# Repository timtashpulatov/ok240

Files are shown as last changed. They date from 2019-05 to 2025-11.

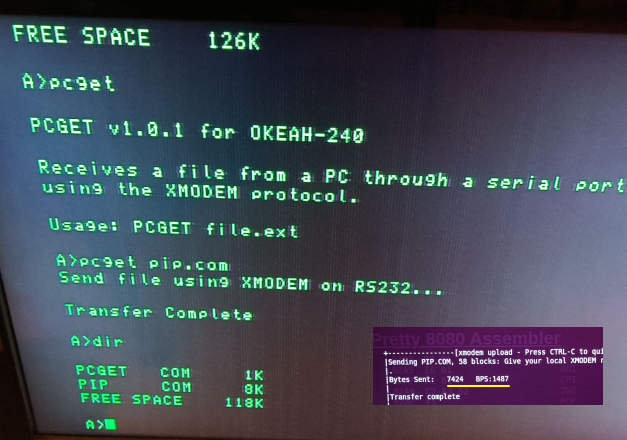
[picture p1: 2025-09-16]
pcget.png

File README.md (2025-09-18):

# ok240

https://svofski.github.io/pretty-8080-assembler/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

https://svofski.github.io/pretty-8080-assembler/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

https://svofski.github.io/pretty-8080-assembler/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

https://svofski.github.io/pretty-8080-assembler/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

https://svofski.github.io/pretty-8080-assembler/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

Literature:

<ul>
<li>https://tetris.fandom.com/wiki/Random_Generator
<li>https://zx-pk.ru/threads/23100-generator-psevdosluchajnykh-chisel/page5.html
<li>https://tetris.fandom.com/wiki/Scoring
<li>https://en.wikipedia.org/wiki/Bit_blit
</ul>

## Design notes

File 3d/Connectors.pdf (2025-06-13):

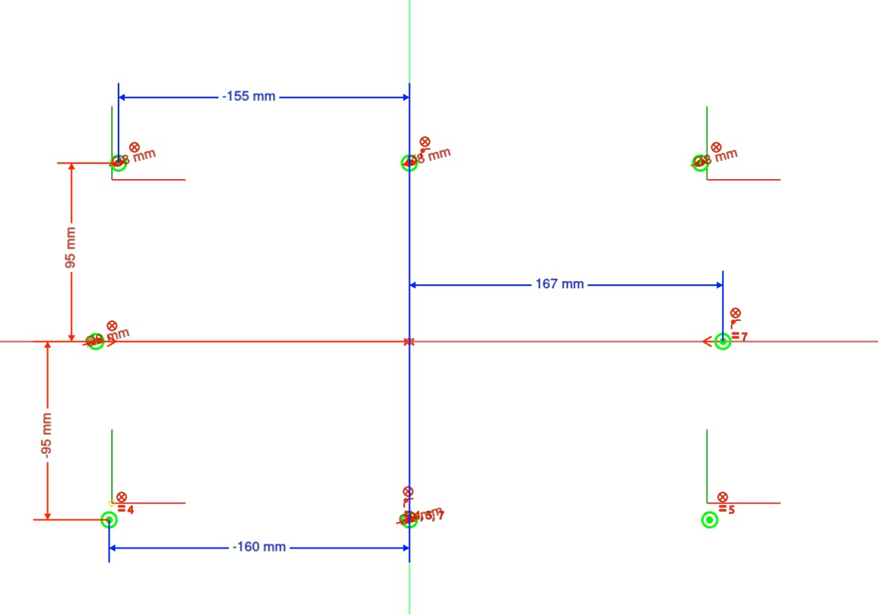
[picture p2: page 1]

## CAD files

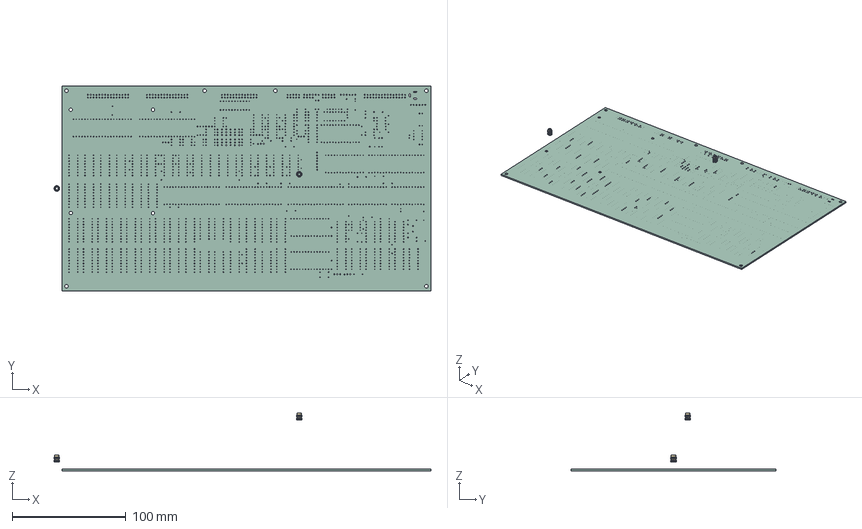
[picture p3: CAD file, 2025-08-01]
3d/Assy.FCStd
332.1 x 180.3 x 51.0 mm
OK240.2-02_PCB002
HotInsert001
HotInsert002

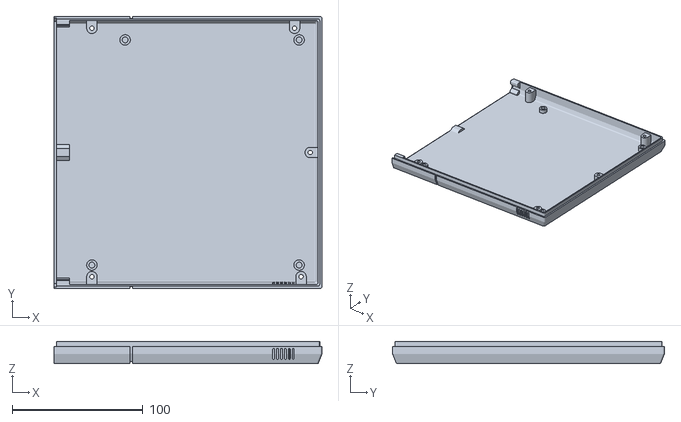
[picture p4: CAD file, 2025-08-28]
3d/stl/bottom-right-20250726.stl
205.0 x 208.0 x 17.0

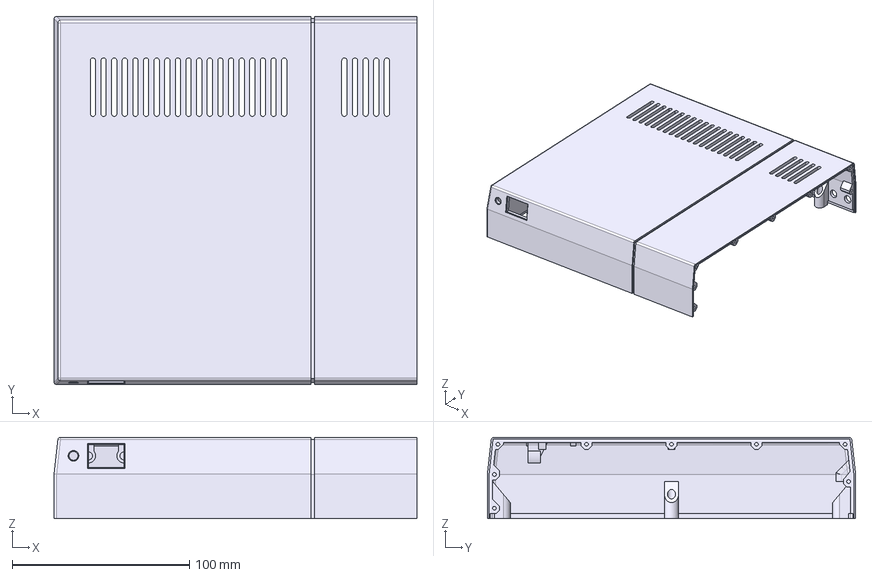
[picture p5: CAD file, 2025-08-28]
3d/TopLeft.FCStd
205.0 x 208.0 x 46.0 mm
LeftMount
FrontSupport
BackSupport
RightMount
Iface tio
Iface left (clone)001
Iface right (clone)001
Mount 1
Mount 2

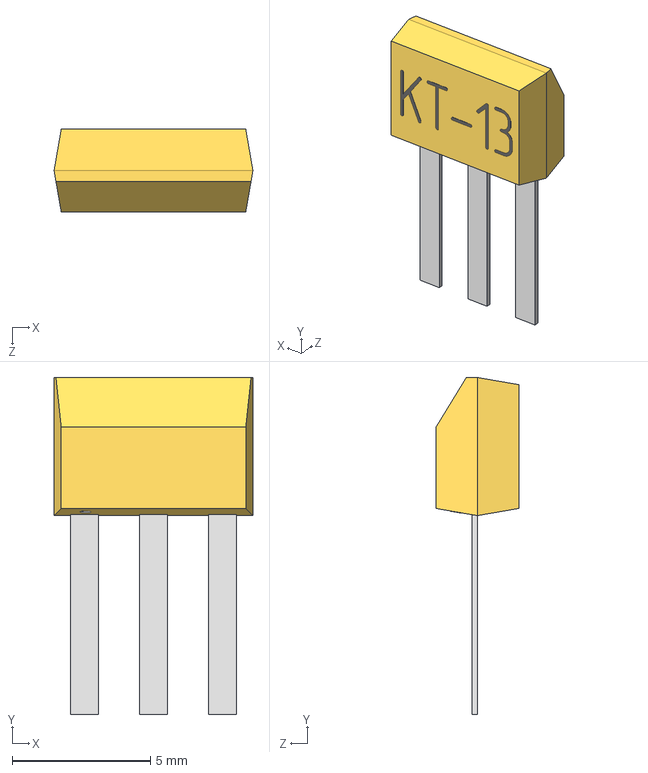
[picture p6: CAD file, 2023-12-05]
pcb/3d/КТ-13.STEP
7.20 x 12.2 x 3.01 mm
扻豵鵨
Âûâîäû ïðÿìûå x 3

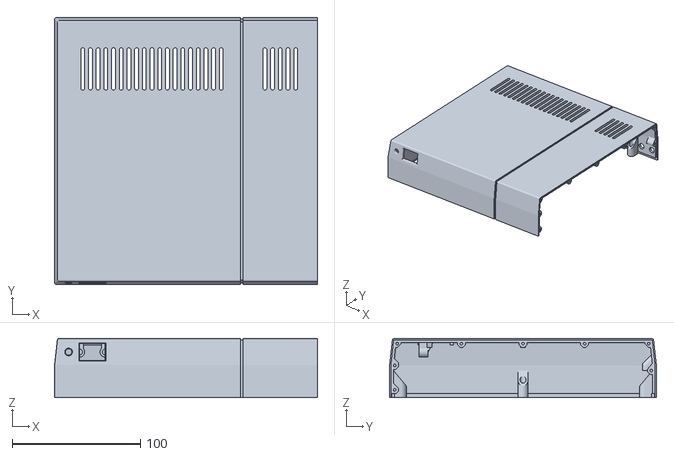
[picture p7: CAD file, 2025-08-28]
3d/stl/top-left-20250823.stl
205.0 x 208.0 x 46.0

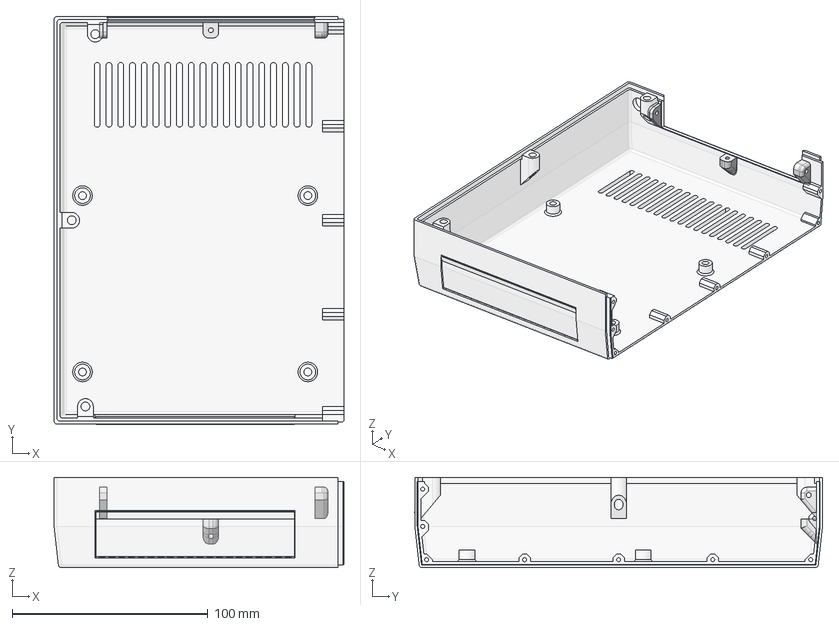
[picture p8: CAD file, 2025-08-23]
3d/TopRight.FCStd
147.9 x 208.2 x 46.0 mm
Kbd001
KbdRight (clone)
Kbd left (clone)

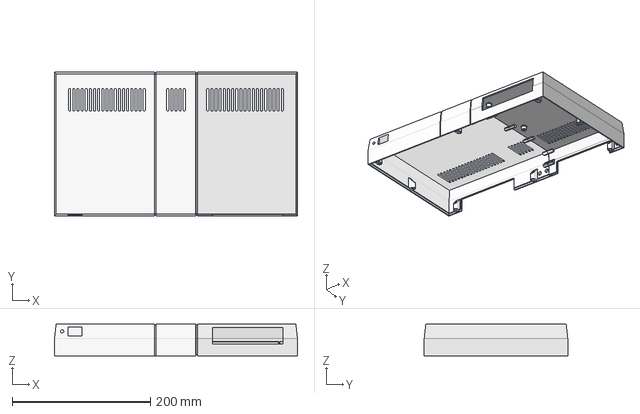
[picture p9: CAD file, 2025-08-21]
3d/CaseTopWithGrooves.FCStd
352.0 x 208.0 x 46.0 mm
Right
Left001

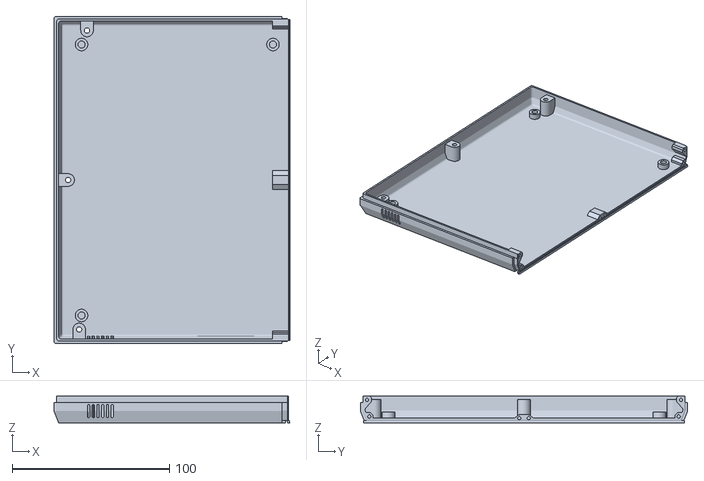
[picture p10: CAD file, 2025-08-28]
3d/stl/bottom-left-20250726.stl
150.0 x 208.0 x 17.0

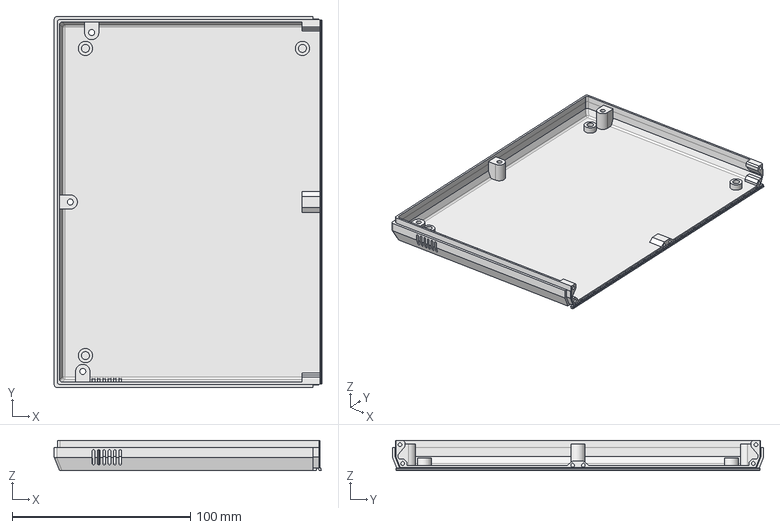
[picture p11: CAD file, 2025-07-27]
3d/CaseBottomWithGroovesAndLock.FCStd
150.0 x 208.0 x 17.0 mm

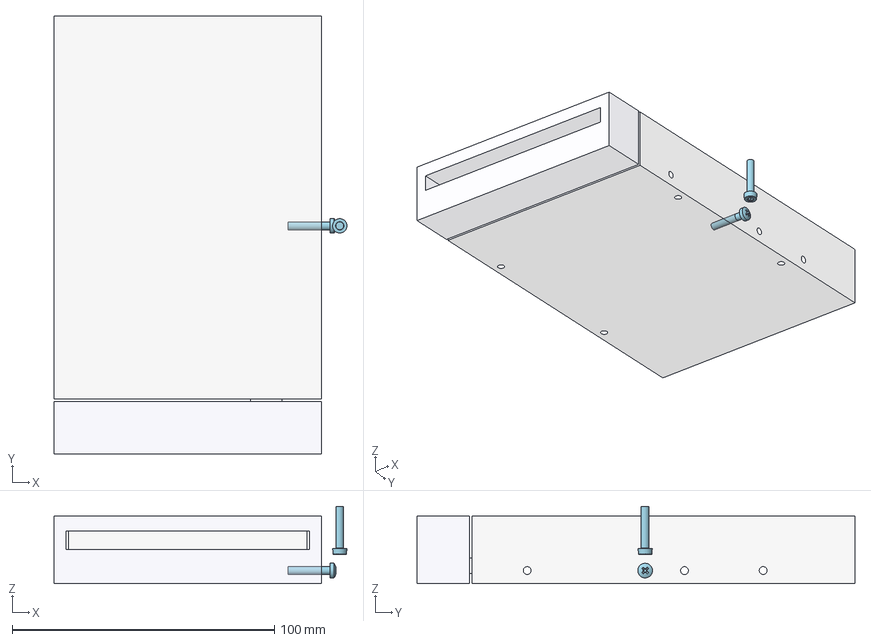
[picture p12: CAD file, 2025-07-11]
3d/FDD.FCStd
111.8 x 167.0 x 29.5 mm
M3x16-Screw
M3x16-Screw001

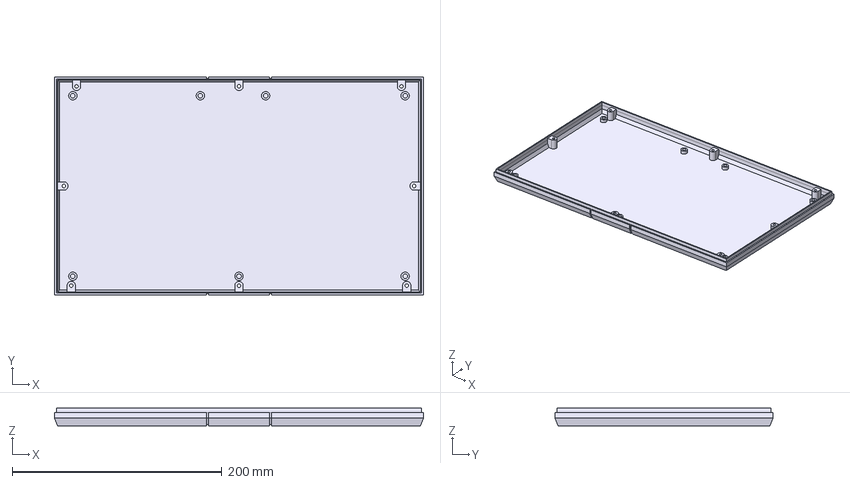
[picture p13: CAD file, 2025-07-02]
3d/CaseBottomWithGrooves.FCStd
352.0 x 208.0 x 17.0 mm

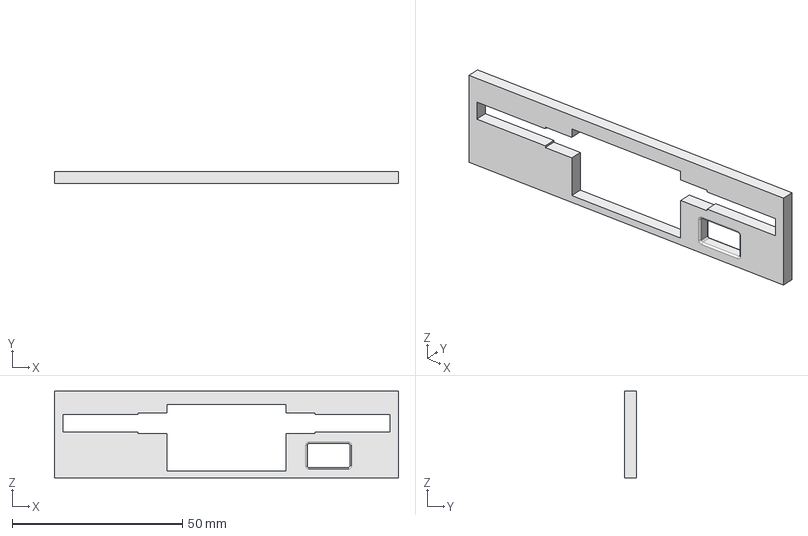
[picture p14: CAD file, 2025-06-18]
3d/Bezel.FCStd
101.0 x 3.50 x 25.4 mm

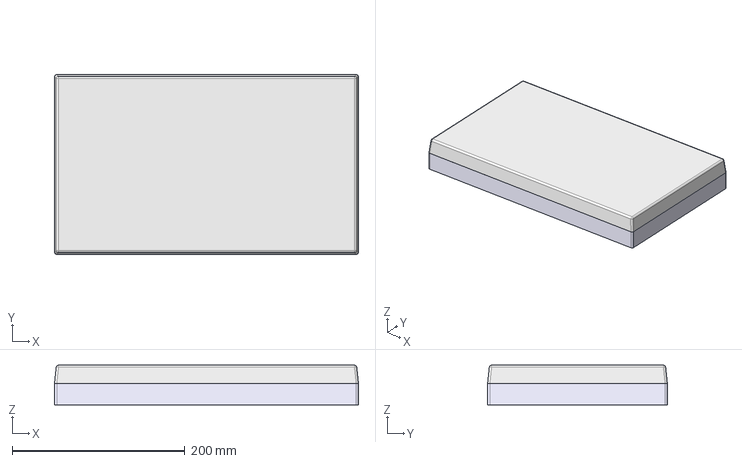
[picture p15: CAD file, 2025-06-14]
3d/CaseTopNew.FCStd
352.5 x 208.5 x 46.0 mm
Top
Mid

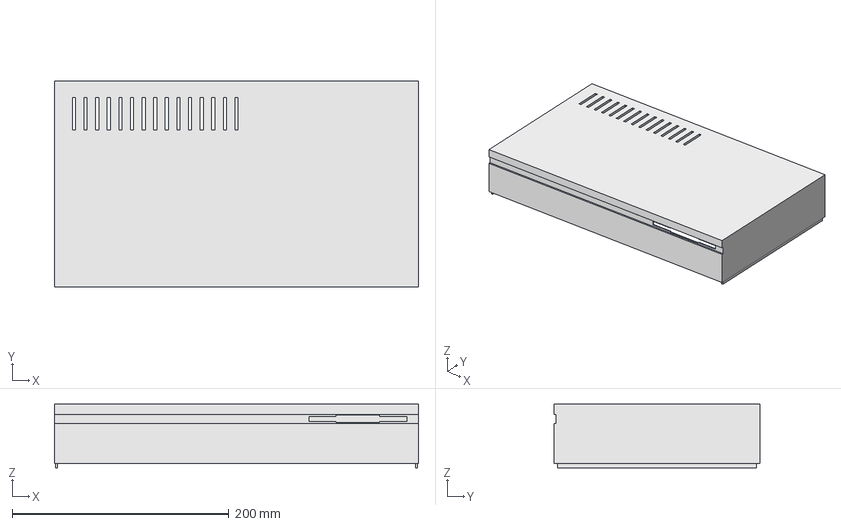
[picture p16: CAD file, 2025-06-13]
3d/CaseTop.FCStd
336.0 x 190.0 x 59.0 mm

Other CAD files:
3d/stl/top-right-20250823.stl
3d/CaseTopNewSolid.FCStd
3d/CaseBottom.FCStd
3d/FloppyFrame.FCStd
3d/FDC.FCStd
3d/PCB.FCStd

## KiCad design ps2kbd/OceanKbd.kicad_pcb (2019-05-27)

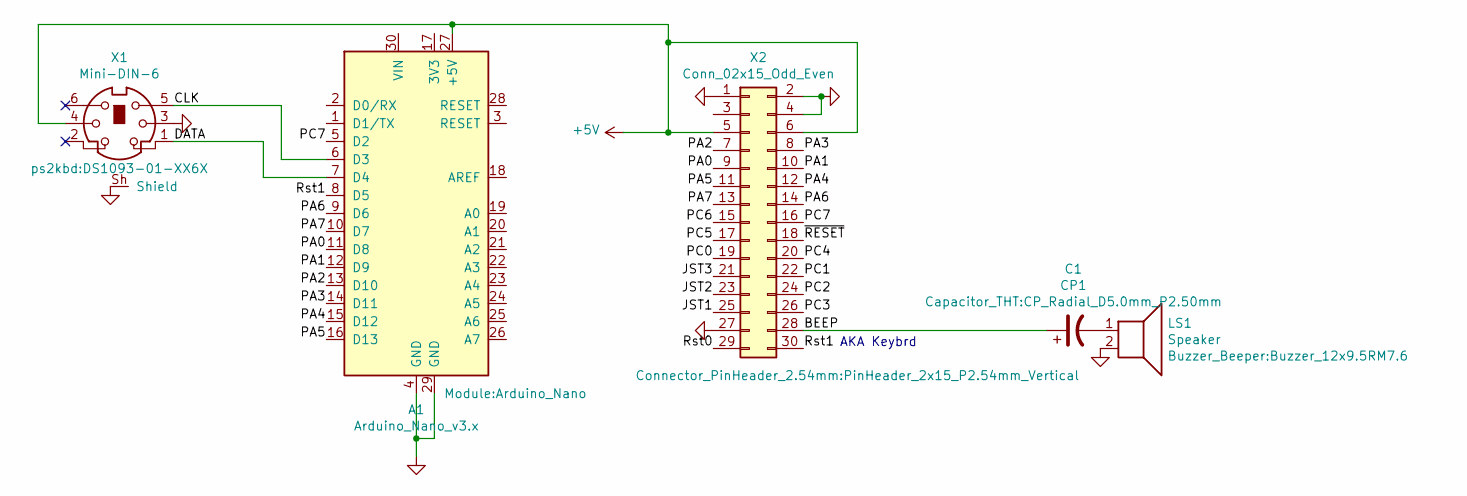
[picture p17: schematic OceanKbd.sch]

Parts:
A1: Arduino_Nano_v3.x; Arduino_Nano
C1: CP1; CP_Radial_D5.0mm_P2.50mm
LS1: Speaker; Buzzer_12x9.5RM7.6
X1: Mini-DIN-6; DS1093-01-XX6X
X2: Conn_02x15_Odd_Even; PinHeader_2x15_P2.54mm_Vertical

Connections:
+5V: A1.27 (+5V), X1.4, X2.5, X2.6
/BEEP: C1.1, X2.28
/CLK: A1.6 (D3), X1.5
/DATA: A1.7 (D4), X1.1
/JST1: X2.25
/JST2: X2.23
/JST3: X2.21
/PA0: A1.11 (D8), X2.9
/PA1: A1.12 (D9), X2.10
/PA2: A1.13 (D10), X2.7
/PA3: A1.14 (D11), X2.8
/PA4: A1.15 (D12), X2.12
/PA5: A1.16 (D13), X2.11
/PA6: A1.9 (D6), X2.14
/PA7: A1.10 (D7), X2.13
/PC0: X2.19
/PC1: X2.22
/PC2: X2.24
/PC3: X2.26
/PC4: X2.20
/PC5: X2.17
/PC6: X2.15
/PC7: A1.5 (D2), X2.16
/Rst0: X2.29
/Rst1: A1.8 (D5), X2.30
/~RESET: X2.18
GND: A1.4 (GND), A1.29 (GND), LS1.2, X1.3, X1.SH, X1.Sh (Shield), X2.1, X2.2, X2.4, X2.27
unnamed: C1.2, LS1.1

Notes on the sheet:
AKA Keybrd

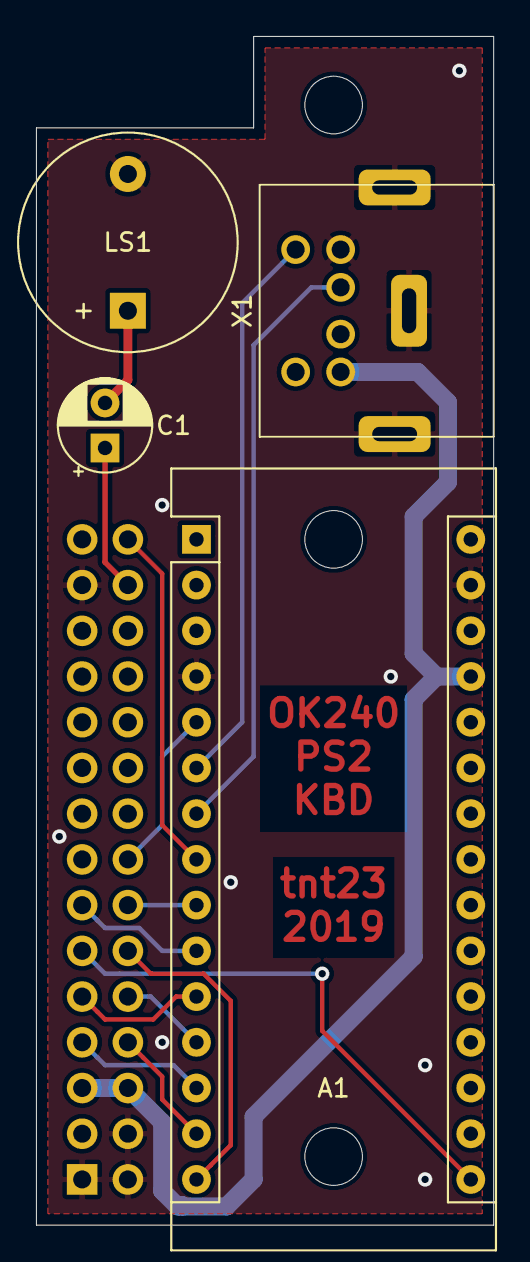
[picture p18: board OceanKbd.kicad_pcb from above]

Board: 2 copper layers, 25.4 x 66.0 mm, 5 parts (1 on the bottom side), 16 nets.

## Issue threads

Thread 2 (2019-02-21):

Изменить кодирование нот

timtashpulatov, 2019-02-21:
Сейчас в коде тупо хранится таблица используемых нот на две октавы, к тому же без полутонов. Лучше хранить хроматическую октаву, где в младшем ниббле кодировать номер ноты, а в старшем номер октавы и еще что-нибудь полезное, например, стаккатовость.

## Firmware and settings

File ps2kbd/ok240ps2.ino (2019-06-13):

#include <PS2KeyAdvanced.h>
#include <PS2KeyMap.h>
#include <PS2KeyData.h>

const int DataPin = 4;
const int IRQpin =  3;
const byte ACKpin = 2;
const int nSTB = 5;

PS2KeyAdvanced keyboard;
PS2KeyMap keymap;


void setup() {

  Serial.begin( 115200 );
  
  // PD5 is low active out strobe
  pinMode (nSTB, OUTPUT);
  digitalWrite (nSTB, HIGH);


  // PD6, PD7 map to Ok240's PA6 and PA7
  pinMode (6, OUTPUT);
  pinMode (7, OUTPUT);


  // PB0-PB5 map to Ok240's PA0-PA5
  pinMode (8, OUTPUT);
  pinMode (9, OUTPUT);
  pinMode (10, OUTPUT);
  pinMode (11, OUTPUT);
  pinMode (12, OUTPUT);
  pinMode (13, OUTPUT);


  // PD2 ACK strobe from OK240's PC7
  pinMode(ACKpin, INPUT_PULLUP);
  attachInterrupt(digitalPinToInterrupt(ACKpin), ClearSTB, RISING);


  // A0 pin as nRESET output
  pinMode (A0, OUTPUT);
  digitalWrite (A0, HIGH);

  keyboard.begin (DataPin, IRQpin);
  
  // Disable Break codes (key release) from PS2KeyAdvanced
  keyboard.setNoBreak (1);
  
  // and set no repeat on CTRL, ALT, SHIFT, GUI while outputting
  keyboard.setNoRepeat( 1 );

  // Typematic rate (0x1f = 2 CPS) and delay (in 0.25s increments)
  keyboard.typematic (0x10, 0);

  // Reset
  Reset ();
}

void Reset () {
  digitalWrite (A0, LOW);
  delay (1);
  digitalWrite (A0, HIGH);  
}


void loop() {


  if (keyboard.available()) {
    
    // read the next key
    int code = keyboard.read();

    Serial.println (code, HEX);
    
    int c = keymap.remapKey(code);
  
    Serial.println (c, HEX);

    Serial.print ("\n");


    if (((c & 0xff) == PS2_DELETE) && (c & PS2_ALT) && (c & PS2_CTRL)) {
    /*if (c == 0x287f) {  */
      Serial.println ("Reset!");
      Reset ();
    };
    
   
      

      /* Remap certain codes */      
      switch (code) {
        case 0x115: c = 8; break;      /* Left */
        case 0x116: c = 0x18; break;   /* Right */
        case 0x117: c = 0x19; break;   /* Up */
        case 0x118: c = 0x1a; break;   /* Down */
        default:
          break;
      }
      
      Serial.println (c, HEX);

      if ((c > 0) && (c < 0x100)) {
      
        if (c & 0x01) {digitalWrite (8, HIGH);} else {digitalWrite (8, LOW);}
        if (c & 0x02) {digitalWrite (9, HIGH);} else {digitalWrite (9, LOW);}
        if (c & 0x04) {digitalWrite (10, HIGH);} else {digitalWrite (10, LOW);}
        if (c & 0x08) {digitalWrite (11, HIGH);} else {digitalWrite (11, LOW);}
        if (c & 0x10) {digitalWrite (12, HIGH);} else {digitalWrite (12, LOW);}
        if (c & 0x20) {digitalWrite (13, HIGH);} else {digitalWrite (13, LOW);}

        if (c & 0x40) {digitalWrite (6, HIGH);} else {digitalWrite (6, LOW);}
        if (c & 0x80) {digitalWrite (7, HIGH);} else {digitalWrite (7, LOW);} // Probably not needed for OK240


        // Strobe low
        digitalWrite (nSTB, LOW);    
      }
  }
}


void ClearSTB () {
    // Strobe high
    digitalWrite (nSTB, HIGH);
  
}

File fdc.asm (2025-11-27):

	.project fdt
	.org 100h

CONST           equ     0e006h  ; A = FF if there is keypress
CONIN           equ     0e009h  
CONOUT          equ     0e00ch  ; output symbol from C


VIDEO           equ     0E1h
ENROM           equ     0x10
SCROLL_V        equ     0C0h
BANKING         equ     0C1h
SCROLL_VH       equ     0C2h


PORT_CMD                equ     20h
PORT_TRACK              equ     21h
PORT_SECTOR             equ     22h
PORT_DATA               equ     23h
PORT_FLOPPY_WAIT        equ     24h
PORT_FLOPPY             equ     25h

DRIVE_0         equ     1 << 0
DRIVE_1         equ     1 << 1
DRIVE_SELECT    equ     1 << 2
DRIVE_INIT      equ     1 << 3
DRIVE_SIDE      equ     1 << 5  ; write to reg 25

DRIVE_MOTST     equ     1 << 7  ; read from reg 25

FLAG_UPDATE     equ     10h

CMD_RESTORE     equ     00h
CMD_SEEK        equ     10h
CMD_STEPIN      equ     40h     ; towards center and track 79
CMD_STEPOUT     equ     60h     ; to track 0
CMD_READADDRESS equ     0c0h    ; read next ID
CMD_READSECTOR  equ     80h
CMD_READTRACK   equ     0e0h    ; read track

STATUS_NOTREADY equ     80h
STATUS_WPROT    equ     40h
STATUS_NOTFOUND equ     10h
STATUS_CRC      equ     08h
STATUS_BUSY     equ     01h

ESC             equ     27
CRLF            equ     00d0ah

SCREEN          equ     0c000h

        ; lxi     d, Help
        ; mvi     c, 9
        ; call     5


        ; mvi     c, '?'
        ; call    CONOUT


        ; call    ResetScroll


; Loop
;         call    ProcessTasks
;         jmp     Loop



        lxi     h, MainMenu
        call    PrintString

        mvi     a, 40h
        out     VIDEO




        lxi     hl, BMP_LOGO
        lxi     bc, 0
        mvi     e, 4
        call    PaintBitmapRow

        lxi     hl, BMP_LOGO + 4*16
        lxi     bc, 0008h
        mvi     e, 4
        call    PaintBitmapRow

        lxi     hl, BMP_LOGO + 8*16
        lxi     bc, 0010h
        mvi     e, 4
        call    PaintBitmapRow




        call    PaintBitmapMxN          ; TODO 

        call    DrawSideIndicator

        call    DrawDiskTemplate

        call    DrawSectorsRuler
        call    DrawSectorsTemplate

        call    DrawDumpTemplate

        mvi     a, 2
        sta     PrintColor

        call    DumpSector

        ; lxi     d, HEX_DASH
        ; lxi     b, 0878h
        ; call    FillTempChar
        ; call    PrintTempChar

        call    PaintFloppyBits

        ; mvi     a, 2
        ; sta     PrintColor

MenuLoop

        ; mvi     a, 1
        ; call    Delay
        
        call    CONST
        inr     a
        jz      WeHaveKeypress
        
        call    ShowFloppyPort
        call    ShowVG93Regs
		
	jmp     MenuLoop


WeHaveKeypress
        call    CONIN
; Большие или малые буквы, это все равно
        cpi     0x5f
        jc      Next0
        sui     0x20
Next0

        mov     c, a
        lxi     d, MenuKeys
Next        
        ldax    d
        ora     a
        jz      MenuLoop
        cmp     c
        jz      Gotcha
        inx     d
        inx     d
        inx     d
        jmp     Next
Gotcha
        inx     d
        ldax    d
        mov     l, a
        inx     d
        ldax    d
        mov     h, a
        mov     a, c
        pchl

MenuKeys
        db      'H' \ dw RestoreHome
        db      '0' \ dw SelectDrive0
        db      '1' \ dw SelectDrive1
        db      'E' \ dw End
        db      'M' \ dw MotorStart
        ; db      '-' \ dw StepOut
        db      1ah \ dw StepOut
        ; db      '+' \ dw StepIn
        db      19h \ dw StepIn
        db      08h \ dw SecPrev
        db      18h \ dw SecNext
        db      'S' \ dw SideToggle
        db      'I' \ dw ReadNextID
        db      'T' \ dw TrackLoop
        db      'R' \ dw SectorRead
        db      'C' \ dw ContinuousDrill
        db      'D' \ dw DiskScan
        db      'W' \ dw WholeTrackRead
        db      ESC \ dw Quit
        db      0 \ dw 0

Quit    rst     0        


; ************************************************************************
; Whole Track Read
; ************************************************************************
WholeTrackRead
        call    _MotorStart
        call    _WaitForIdle
        ora     a
        jz      MenuLoop

        mvi     a, CMD_READTRACK
        out     PORT_CMD

        lxi     h, 4000h
        call    ReadDataLoop

        lxi     h, 4000h + 80
        lxi     b, 08b0h
        mvi     e, 64
        call    DumpHexBlock



        jmp     MenuLoop
        
; ************************************************************************
; Disk scan
; ************************************************************************
DiskScan

        call    DrawDiskTemplate

        call    _MotorStart
        call    _WaitForIdle
        ora     a
        jz      MenuLoop

        call    _Restore
        call    _WaitForIdle
        
        xra     a
        out     PORT_TRACK
DSLoop
        call    _TrackLoop

        ora     a
        in      PORT_TRACK
        jz      DSLOk0
        ori     80h
DSLOk0
        call    DrawTrack
        call    _SideToggle
        
        call    _TrackLoop

        ora     a
        in      PORT_TRACK
        jz      DSLOk1
        ori     80h
DSLOk1
        call    DrawTrack
        call    _SideToggle

        call    CONST
        inr     a
        jz      DSDone

        call    _StepIn
        call    _WaitForIdle
        
        in      PORT_TRACK
        cpi     80
        jnz     DSLoop

DSDone
        call    _Restore
        call    _WaitForIdle

        jmp     MenuLoop

; ************************************************************************
; Draw Disk Template
; ************************************************************************
DrawDiskTemplate
        lxi     b, (TRACK_GAUGE_X*2 << 8) + TRACK_GAUGE_Y        ;0c08h
        lxi     hl, BMP_4TRACK_TEMPLATE
        mvi     e, 20
        call    PaintRowOfSameBitmap

        lxi     b, (TRACK_GAUGE_X*2 << 8) + TRACK_GAUGE_Y - 8
        lxi     hl, BMP_4TRACK_TEMPLATE
        mvi     e, 20
        call    PaintRowOfSameBitmap
        
        lxi     b, ((TRACK_GAUGE_X - 1)*2 << 8) + TRACK_GAUGE_Y - 4
        lxi     hl, BMP_TRACK_00
        mvi     a, 3
        call    PaintBitmap

        lxi     b, ((TRACK_GAUGE_X + 20)*2 << 8) + TRACK_GAUGE_Y - 4
        lxi     hl, BMP_TRACK_79
        mvi     a, 3
        call    PaintBitmap
        
ret

; ************************************************************************
; Draw track
; ************************************************************************
; A = track number
; bit 7 set for BAD track
DrawTrack

TRACK_GAUGE_X   equ     6
TRACK_GAUGE_Y   equ     80+32+8      ;16
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

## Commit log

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2019-02-10 Исправлен глюк с цветом присохшей фигуры
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2019-04-07 Исправлен вертикальный отскок
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2019-05-29 Исправил отскок от границ экрана
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2019-07-09 Исправлена бага с кирпичами ниже 16 строки
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2023-10-31 Fixed bug with 170AP3 pin 4
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2023-12-05 Change footprints and 3d models for KT315 and KT361
    [КТ-13.STEP]
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2023-12-19 +12V PSU redesign
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2025-06-01 Case parts
    [CaseBottom.FCStd, CaseTop.FCStd, FDC.FCStd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]
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2025-06-02 Update floppy support part, misc 3d stuff
    [CaseBottom.FCStd, FDD.FCStd, FloppyFrame.FCStd]
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2025-06-07 Add more cutouts to floppy frame
    [FloppyFrame.FCStd]
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2025-06-12 Another approach to bottom lid
    [CaseBottom.FCStd]
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2025-06-13 More Tops and drawings
    [CaseTopNew.FCStd, CaseTopNewSolid.FCStd]
2025-06-14 Update for top lid posts
    [CaseTopNew.FCStd, CaseTopNewSolid.FCStd]
2025-06-14 Add stringers to pillars
    [CaseTopNewSolid.FCStd]
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2025-06-18 More updates to bottom lid
    [CaseBottom.FCStd]
2025-06-19 Simplified bottom with stands
    [CaseBottom.FCStd]
2025-06-19 Redesign bottom and top halves
    [CaseBottom.FCStd, CaseTopNewSolid.FCStd]
2025-06-20 Cleaned top and bottom lids
    [CaseBottom.FCStd, CaseTopNewSolid.FCStd]
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2025-06-20 Enhance side bracket with some chamfering
    [FDD.FCStd]
2025-06-21 Update side bracket, add mount posts to top lid
    [CaseTopNewSolid.FCStd, FDD.FCStd]
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2025-06-27 Add lip to bottom lid
    [CaseBottom.FCStd]
2025-06-27 PCB mount holes on lower lid
    [CaseBottom.FCStd]
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2025-07-02 New top and bottom parts with grooves
    [CaseBottomWithGrooves.FCStd, CaseTopWithGrooves.FCStd]
2025-07-11 Three locks added for bottom part
    [CaseBottomWithGroovesAndLock.FCStd]
2025-07-12 Chamfer top alignment pads, add dowel pin for reference
    [CaseBottomWithGroovesAndLock.FCStd]
2025-07-12 Use split halves as new Left and Right features
    [CaseBottomWithGroovesAndLock.FCStd]
2025-07-12 Make lock pad two-dimentional and shift it for symmetry
    [CaseBottomWithGroovesAndLock.FCStd]
2025-07-12 Add dowel holes to left half
    [CaseBottomWithGroovesAndLock.FCStd]
2025-07-12 Shape dowel holes as drops for better printing and mirror them
    [CaseBottomWithGroovesAndLock.FCStd]
2025-07-12 Teardrop dowel holes properly redone as features
    [CaseBottomWithGroovesAndLock.FCStd]
2025-07-19 Add vents to Left bottom part
    [CaseBottomWithGroovesAndLock.FCStd]
2025-07-20 Rename vents feature to Vents
    [CaseBottomWithGroovesAndLock.FCStd]
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2025-07-22 Fix left vents
    [CaseBottomWithGroovesAndLock.FCStd]
2025-07-25 Add 1mm chamfer to left bottom part, to reduce elephant foot etc
    [CaseBottomWithGroovesAndLock.FCStd]
2025-07-25 Change bottom chamfer for 45 degrees, add 1mm fillets
    [CaseBottomWithGroovesAndLock.FCStd]
2025-07-25 Add right angle IDC 30-pin connector 3D models
    [OK240.2-02.kicad_pcb]
2025-07-25 Fix lip chamfer and fillets
    [CaseBottomWithGroovesAndLock.FCStd]
2025-07-25 Add fillets to right bottom part
    [CaseBottomWithGroovesAndLock.FCStd]
2025-07-26 Increase fillet radius to 1.5mm
    [CaseBottomWithGroovesAndLock.FCStd]
2025-07-26 Increase fillet radius to 1.5mm for Left bottom part
    [CaseBottomWithGroovesAndLock.FCStd]
2025-07-27 Add cutouts for power button and LED
    [CaseTopWithGrooves.FCStd]
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2025-07-29 Add stand with heat insert for power switch
    [CaseTopWithGrooves.FCStd]
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2025-08-01 Fix left heat insert pocket on Power switch mount
    [CaseTopWithGrooves.FCStd]
2025-08-01 Update Power switch mount with support
    [CaseTopWithGrooves.FCStd]
2025-08-01 Add Power button mount part to Assembly
    [Assy.FCStd]
2025-08-01 Add Keyboard cutouts, update PCB with connector models
    [CaseTopWithGrooves.FCStd]
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2025-08-02 Add plug for Video and Kbd cutout, and screw mount for it
    [CaseTopWithGrooves.FCStd]
2025-08-02 Video and kbd slot screw mount done
    [CaseTopWithGrooves.FCStd]
2025-08-02 Clean up VideoKbd mount hierarchy
    [CaseTopWithGrooves.FCStd]
2025-08-02 Add left slot mount
    [CaseTopWithGrooves.FCStd]
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2025-08-02 More rear panel connectors
    [CaseTopWithGrooves.FCStd]
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2025-08-04 Make combined cutout for Interface and Kbd
    [CaseTopWithGrooves.FCStd]
2025-08-05 Modify panel cutout ribs, clone panel
    [CaseTopWithGrooves.FCStd]
2025-08-05 Add DC 2.1mm M8 panel socket
    [CaseTopWithGrooves.FCStd]
2025-08-09 Update rear cutouts and panels
    [CaseTopWithGrooves.FCStd]
2025-08-09 Add recess to panels bottom
    [CaseTopWithGrooves.FCStd]
2025-08-09 Add latches and tooth for panel (experimental), add RCA socket for Tape interface
    [CaseTopWithGrooves.FCStd]
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2025-08-13 Thicken hinges a bit
    [CaseTopWithGrooves.FCStd]
2025-08-15 Round internal edge of panels; add lots of locks and mounts to test
    [CaseTopWithGrooves.FCStd]
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2025-08-15 Reshape DSub cutouts, update screw mount stand
    [CaseTopWithGrooves.FCStd]
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2025-08-16 Add left and right screw mounts to Interface and Kbd panels
    [CaseTopWithGrooves.FCStd]
2025-08-16 Update panel screw mounts for 8mm self taping screws
    [CaseTopWithGrooves.FCStd]
2025-08-16 Vents for top lid
    [CaseTopWithGrooves.FCStd]
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2025-08-21 Update left and right slices, so far with rim gap
    [CaseTopWithGrooves.FCStd]
2025-08-21 Interface between left and right parts complete
    [CaseTopWithGrooves.FCStd]
2025-08-22 Add separate file for Top Right part
    [TopRight.FCStd]
2025-08-23 Deepen screw hole on left Interface body mount
    [TopRight.FCStd]
2025-08-23 Update floppy bezel with cutouts
    [TopRight.FCStd]
2025-08-23 Welcome Top Left slice document, kinda release candidate for printing
    [TopLeft.FCStd]
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2025-10-17 Update graf.asm
    Fix preview drawing code
    Add interrupt cheer
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2025-11-15 Reset side when homing
    [fdc.asm]
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
